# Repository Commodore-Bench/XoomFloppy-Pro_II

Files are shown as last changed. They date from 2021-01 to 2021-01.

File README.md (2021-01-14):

# XoomFloppy Pro II

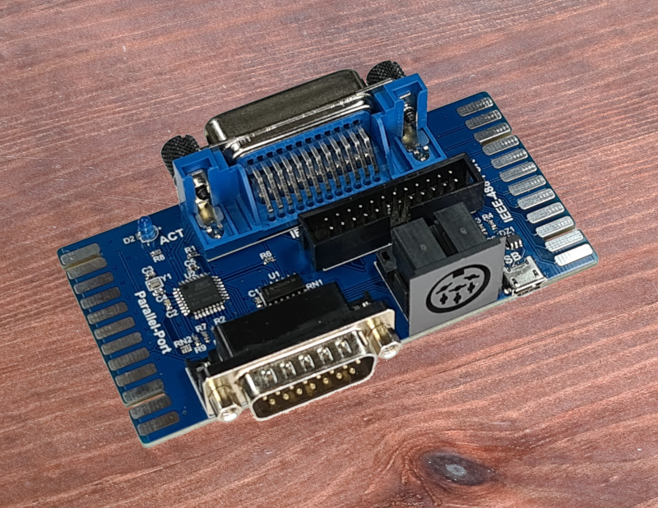
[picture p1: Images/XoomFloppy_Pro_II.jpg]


In 2018, I had developed the first [XoomFloppy Pro](https://github.com/DL2DW/XoomFloppy_Pro_2018). A XUM1541, but which is 100% compatible with the [ZoomFloppy](http://store.go4retro.com/zoomfloppy/) and also requires the same firmware.

Over time, I had then made some improvements. So I have now attached all components on the upper side. Then I added a Centronics connector for the IEEE-488 interface, so that the usual standard GPIB cables can be used. 

This made the XoomFloppy Pro II a little bit wider, and it is now 99,6 x 50,3mm (ZoomFloppy = 118,3x77,5mm). This is still within the size that is fairly inexpensive from the board manufacturers.

## Interfaces

On the one hand there is the CBM bus known from the VIC20, C64 and C128 in form of the 6pin DIN socket. In addition, the connection for a floppy speeder with parallel cable is available as a PCB connector (analog to the user port of the C64/C128), as well as a DSUB25 connector.

Furthermore, an IEEE-488 (GPIB) interface is on board, which is also available as a platinum connector (like on the PET and CBM devices), Centronics socket and pin header (IDC connector).

Of course, only one of the two interfaces can be used at a time. So either CBM bus with additional parallel cable OR IEEE-488.

## Assembly

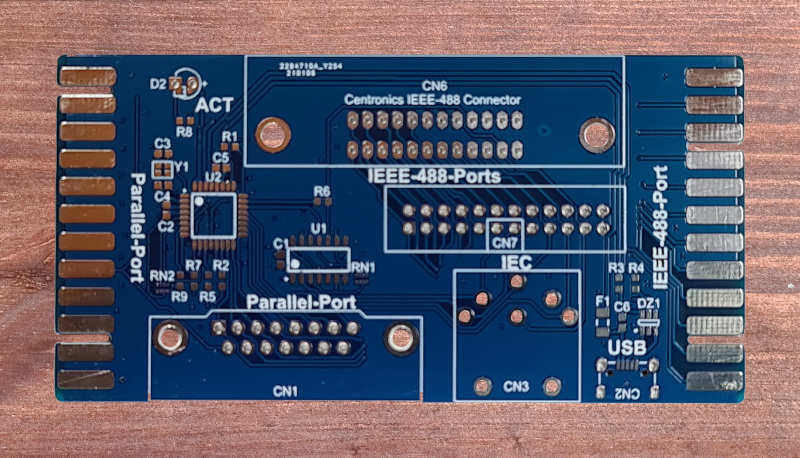
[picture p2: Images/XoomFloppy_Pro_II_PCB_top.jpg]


First of all, the SMD parts should be assembled in descending order of size. So first the ATMega, then the 75LS06, etc. 

And only then the sockets and connectors. I have left as much space as possible between the individual components, so that even less experienced should be able to assemble this board without problems.

For overview a 3D picture of the assembled board:

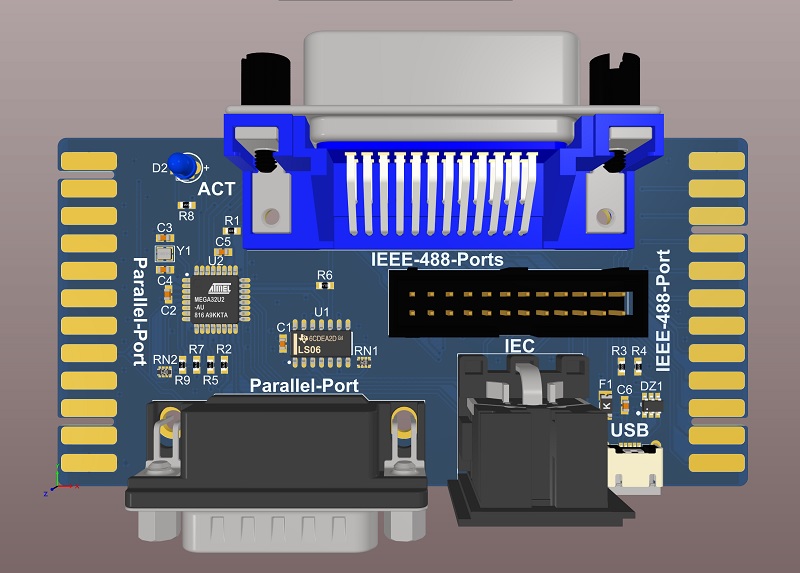
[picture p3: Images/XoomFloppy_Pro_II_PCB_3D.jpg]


The completely assembled board looks like this:

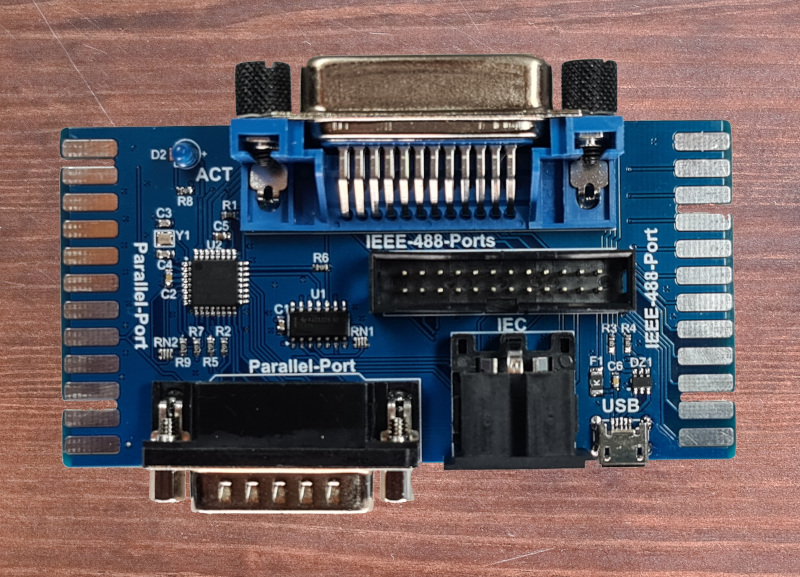
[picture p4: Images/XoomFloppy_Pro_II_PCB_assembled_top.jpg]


## Firmware

The [firmware](https://github.com/OpenCBM/OpenCBM) is flashed via USB analog to the ZoomFloppy. The [openCBM](https://spiro.trikaliotis.net/Download/opencbm-0.4.99.103/opencbm-0.4.99.103.zip) package is required for operation. The instructions for openCBM can be found at https://opencbm.trikaliotis.net/

## BOM

Here is the list of components needed. I have chosen the manufacturers as examples. Of course, compatible components from other manufacturers can also be selected.

| Quantity | Designator | Manufacturer | Manufacturer  Part Number  | Description |
| --- | --- | --- | --- | --- |
| 1 | C5 | KEMET | C0603C105K3RACTU | KEMET  1F Multilayer Ceramic Capacitor (MLCC) 25 V 10% X7R dielectric C SMD max op.  temp. +125C |
| 1 | CN1 | HARTING  Technology  | 09642237802 | HARTING 09 64 223 7802 Filtered D Sub Connector,  Ferrite, DA, Plug, 15 Contacts, 0 F, Steel Body |
| 1 | CN2 | Wurth  Electronics | 629105150521 | Socket  micro-USB B 5P, 629105150521, Würth Elektronik |
| 1 | CN3 | Lumberg | 010599  06 | DIN  chassis socket, right angle version, with ground contact, suitable for  locking, for printed circuit boards |
| 1 | CN6 | L-Com | CIB24SRA | L-COM  - CIB24SRA - CONNECTOR GPIB R/A FEMALE |
| 1 | CN7 | Samtech  Inc. | TST-112-01-G-D | IEEE-488 IDC  Connector Right Angle or Straight |
| 1 | D1 | Wurth  Electronics | 150060BS55040 | LED  BLUE DIFFUSED 0603 SMD |
| 1 | D2 | Wurth  Electronics | 151033BS03000 | WURTH  ELEKTRONIK  151033BS03000  LED, 3MM, BLUE, 3800MCD, 470NM |
| 1 | DZ1 | STMicroelectronics | USBLC6-2SC6 | TVS  DIODE 5.25V 17V SOT23-6 |
| 1 | F1 | Littelfuse | 1206L150THWR | PTC  RESET FUSE 8V 1.5A 1206 |
| 1 | R1 | Yageo | RC0603FR-0710KL | RES  SMD 10K OHM 1% 1/10W 0603 |
| 1 | R8 | Yageo | RC0603FR-07220RL | RES  SMD 220 OHM 1% 1/10W 0603 |
| 1 | U1 | Texas  Instruments | SN74LS06DR | IC  INVERTER OPEN COL 6CH 14SOIC |
| 1 | U2 | Microchip  / Atmel | ATMEGA32U2-AU | ATMEL ATMEGA32U2-AU MCU, 8BIT, MEGAAVR, 16MHZ,  TQFP-32 |
| 1 | Y1 | Raltron  Electronics | R2016-16.000-9-1010-TR-NS1 | 16MHz  ±10ppm 9pF 200Ω SMD,2.0x1.6mm SMD Crystal Resonators RoHS |
| 2 | C3,  C4 | KEMET | C0603C220J5RACTU | 22.0PF  50.0V |
| 2 | R3,  R4 | Yageo | RC0603FR-0722RL | RES  SMD 22 OHM 1% 1/10W 0603 |
| 2 | RN1,  RN2 | Yageo | TC124-FR-07100KL | RES  ARRAY 4 RES 100K OHM 0804 |
| 3 | C1,  C2, C6 | KEMET | C0603C104J3RACTU | KEMET C0603C104J3RACTU SMD Multilayer Ceramic  Capacitor, 0603 [1608 Metric], 0.1 F, 25 V, 5%, X7R, C Series |
| 5 | R2,  R5, R6, R7, R9 | Yageo | RC0603FR-074K7L | RES  SMD 4.7K OHM 1% 1/10W 0603 |

## PCB

The PCB can either be ordered directly from [PCBWay](https://www.pcbway.com/project/shareproject/XoomFloppy_Pro_II.html), or you can create it yourself from the Gerber files available here.

PCBWay (https://www.pcbway.com/project/shareproject/XoomFloppy_Pro_II.html)

If you liked my project, I would be very happy about a small coffee donation.



# License

The contents of this repository, with the exception of the Docs and Software directories, are released under the following license:

- the "Creative Commons Attribution-NonCommercial-ShareAlike 4.0 International License" (CC BY-NC-SA 4.0) full text of this license is included in the [LICENSE.CC-NC-BY-SA-4.0](https://github.com/DL2DW/XoomFloppy-Pro_II/blob/main/LICENSE.CC-NC-BY-SA) file and a copy can also be found at https://creativecommons.org/licenses/by-nc-sa/4.0/

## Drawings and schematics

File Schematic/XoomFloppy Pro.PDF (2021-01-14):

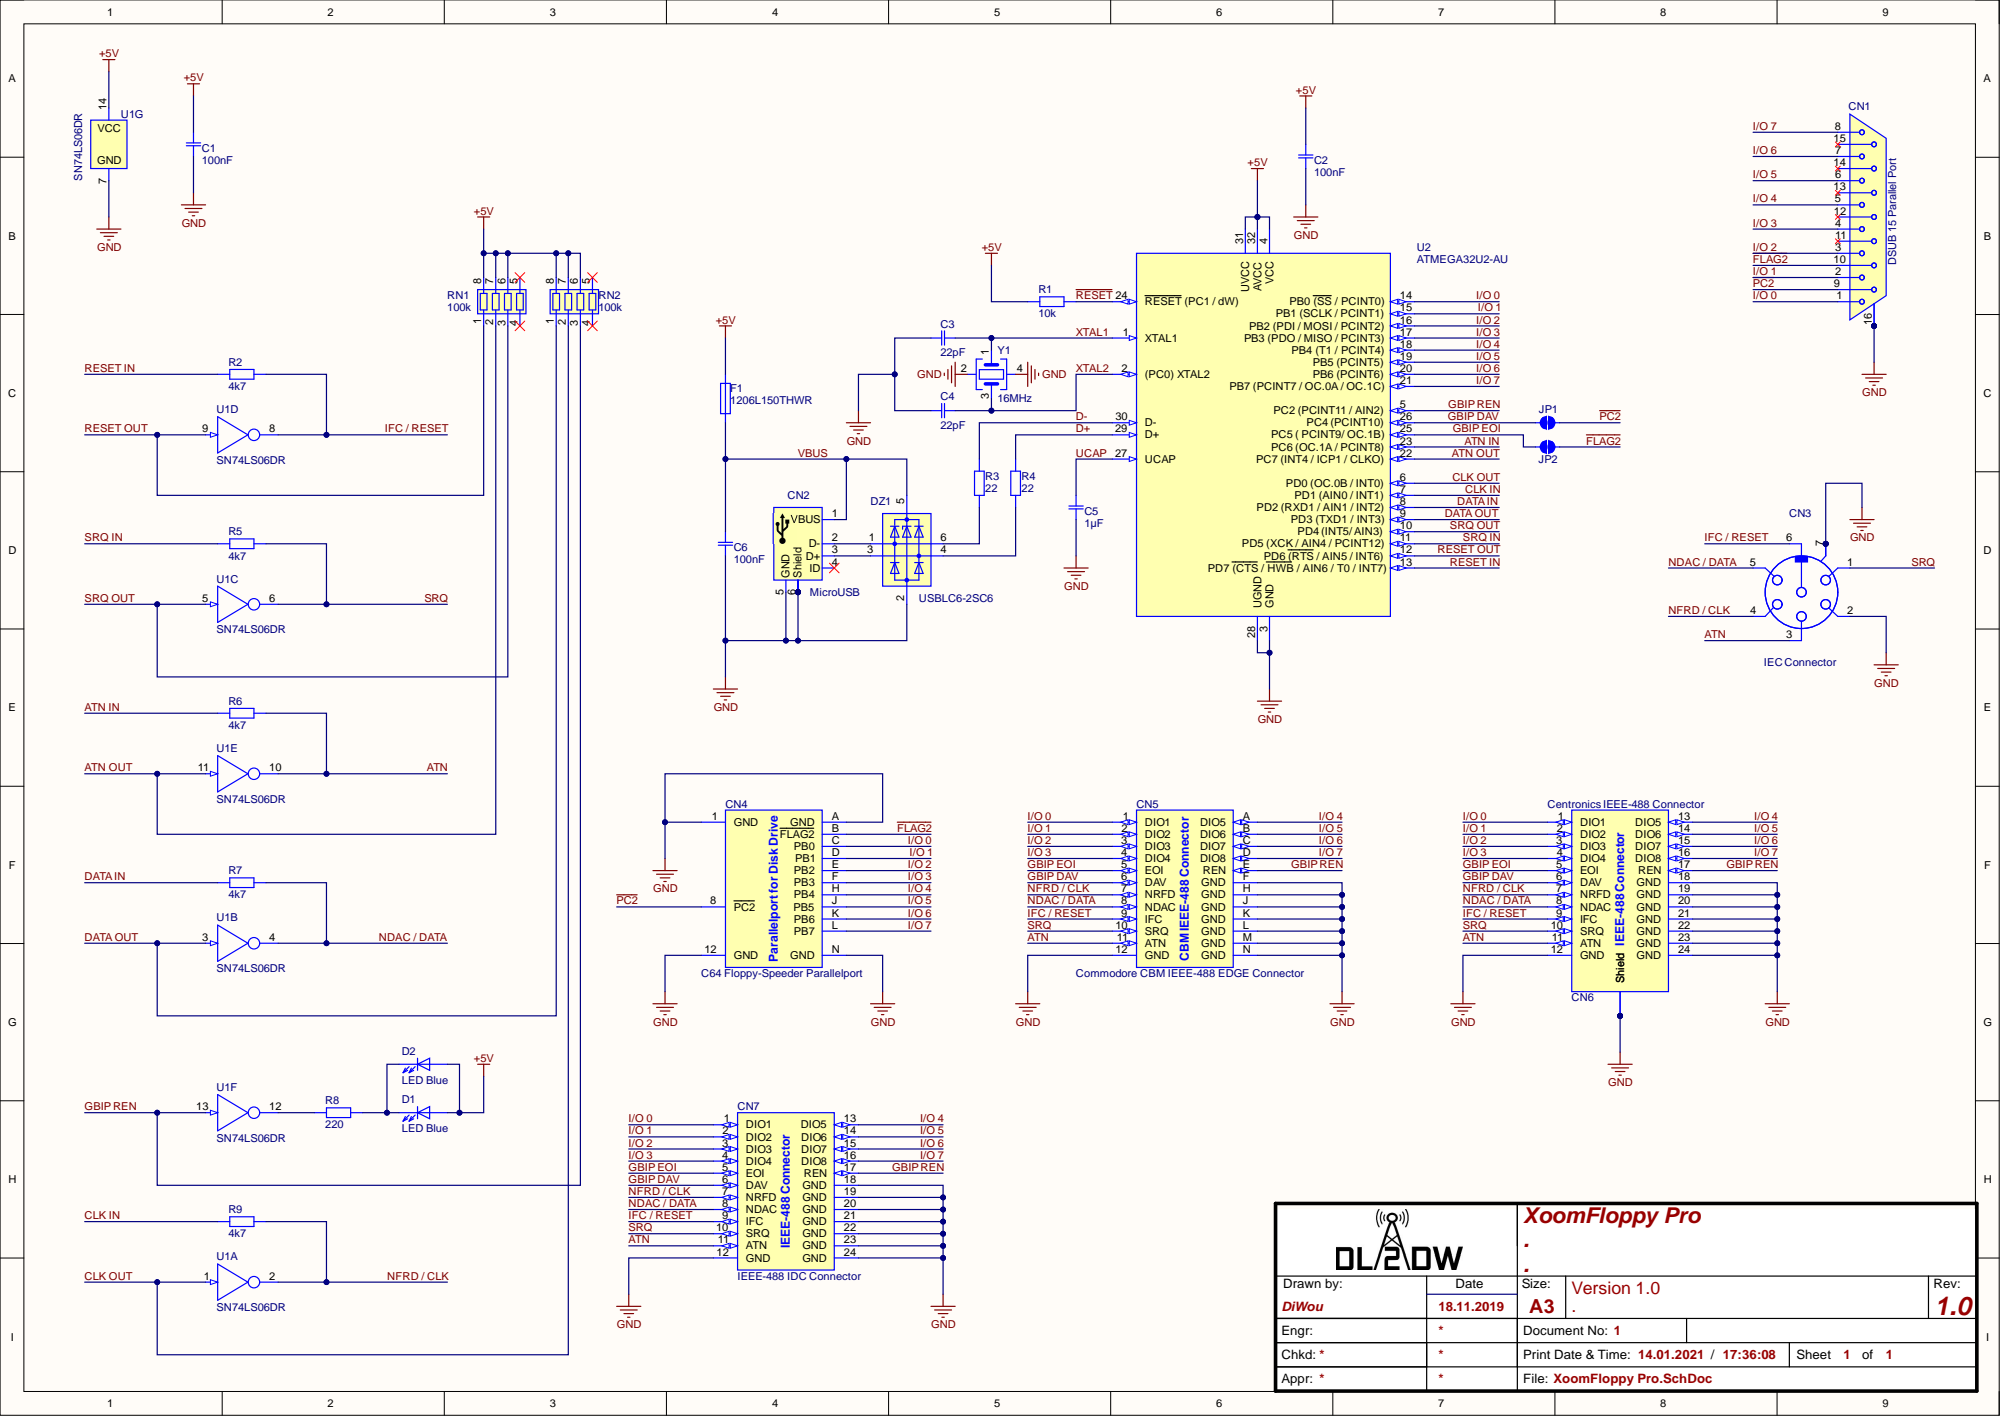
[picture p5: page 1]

GBIP EOI ATN IN ATN OUT CLK OUT CLK IN DATAIN DATA OUT

Parallelport for Disk Drive

Engr : | ** | Document No: 1

Chkd: * | | P rint Date & Time: 14.01.202 1 / 17:36: 0 8 | Sheet 1 of 1

Appr : * | * | o o m Flo p p y P r o.SchDo c

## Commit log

2021-01-14 PCB order link added
2021-02-19 New Gerber files due to offset VIA holes
    [XoomFloppy Pro.GBL, XoomFloppy Pro.GBO, XoomFloppy Pro.GBP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]
